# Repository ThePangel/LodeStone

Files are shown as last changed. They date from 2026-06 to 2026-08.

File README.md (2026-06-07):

# LodeStone

Don't lose your friends with this GPS LoRa P2P compass!

---

## The Idea 

### Where it came from
Just recently my district's fair started, and between all the crowds and the size of the fairgrounds It's pretty hard to find my friends, especially when we get separated, so with that and me playing a bunch of Minecraft this idea of a Mesh LoRa P2P compass came about.

The name is a reference to the lodestone block in Minecraft which lets you set custom compass targets.

---

### Features

- [ ] Compass like display pointing at the other nodes in the mesh network
- [ ] Top down map-like view of all nodes in the network
- [ ] Encrypted location data 
- [ ] Gesture based navigation using the gyroscope and accelerometer
- [ ] Short messages (Using some sort of keyboard using the gestures, or morse code)
- [ ] Heavily optimized battery life

---

### How would it work?
The device consists of 7 components:
- Seeed Studio XIAO ESP32 S3 Plus (As the brains of the device)
- Seeed Studio Lora32 SX1262 (For LoRa)
- Seeed Studio L76K GNSS Module (For GPS)
- GY-9250 BMP085 Module (For Accelerometer, Gyroscope and an actual compass)
- GC9A01 Round TFT screen 
- 503040 600mAh Battery
- Flexible antenna for the gps module (The standard ceramic one that comes with the module is far too bulky)

#### Connectivity 

The idea is that each node connects to each other individually or in groups, working simultaneously.

Pairing is done by a gesture password consisting of holds and taps, basically a morse code pin. You pair your devices using the same pin, then they handshake, share keys, and establish a connection.

Even if they are not paired (and if enabled), nodes retransmit incoming data packets to other users in the network to increase range.

#### Display 

The compass and map are drawn by taking GPS data from both nodes and the GY-9250 compass and accelerometer to calculate the direction the other node is at.

#### Battery

To optimize battery life and not saturate the airwaves, my system uses a Supply-demand approach. When the node (as a pendant or in the pocket) is still and facing away from the user, it is just listening for either location packets or a request packet. If it receives a location packet, it will update that node's location in memory and nothing else. If it receives a request packet, it will send its own location.

When the node is pulled up to be viewed, it will send a request packet to other nodes to update their location in memory, and a location packet so other nodes update it's location. It will do this at customizable intervals of time while it is being viewed. For signal integrity, the sending node must receive a confirmation packet back to ensure the transmission was successful. This workflow keeps battery usage to a minimum.

I still think it should ping at a set interval to guarante some type of connection, since maybe I can recieve my friends location, but he can't recieve my request so I knever know were he is
this could be also tied to speed using the accelerometer, this meaning, the more they move the more they send, if they are still it will default to some configurable interval

We could also tune transmition gain baised on distance, with some headroom of course

#### Interface

To maintain a compact formfactor, interaction with the node will be based on gestures, using the GY-9250 accelerometer and gyro.

Some of this gestures could be:
-   Tap/Double Tap
-   Shake
-   Tilt right/left/up/down

The menus would be similar to a smart watch.

#### Messaging

We can leverage our LoRa connection to send quick preconfigurable messages or write one at that moment using a gesture keyboard or morse code.

In the future I may develop an app to make this easier (tbh just use meshtashtic or meshcore atp), but this is intended for short notification like messages.

I would also like to add an SOS function that sends a signal to all nodes paired, or even if enabled on both ends, all nodes in the network, this will make the nodes flash red and highlight the SOS'ing node.

#### PCB 

The PCB is a simple 4 layer PCB that as compactly as possible houses all of the off the shelf components, making it very cheap and easy to assemble, the two outter planes hold traces and GND while the two inner layers are full ground pours, a bunch of vias connect the 4 GNDs to improve RF performance

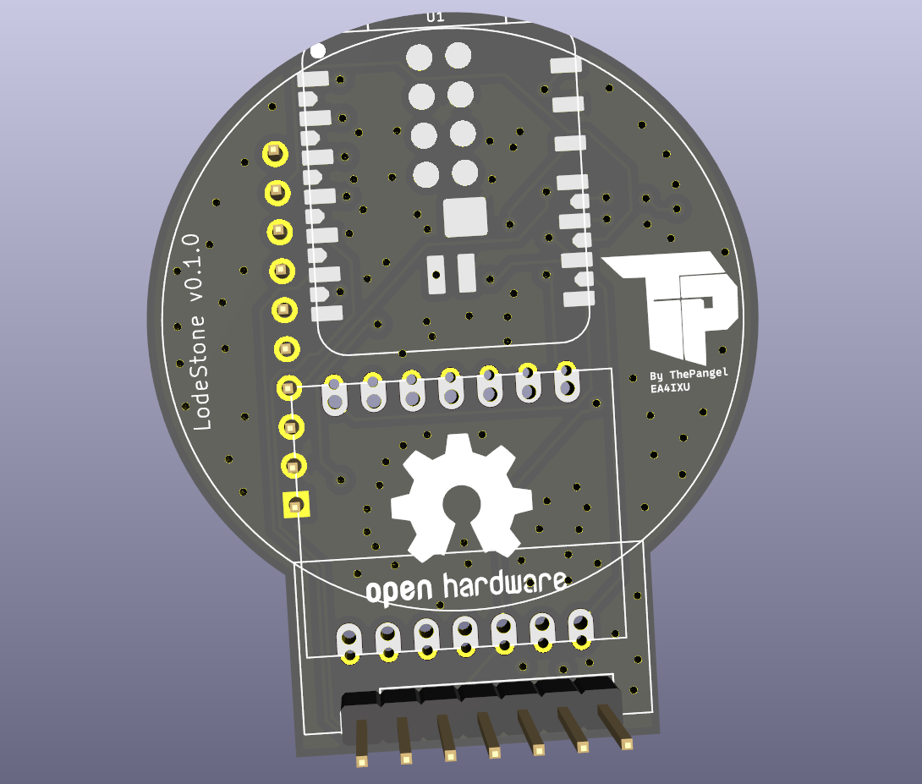
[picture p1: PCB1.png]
PCB1

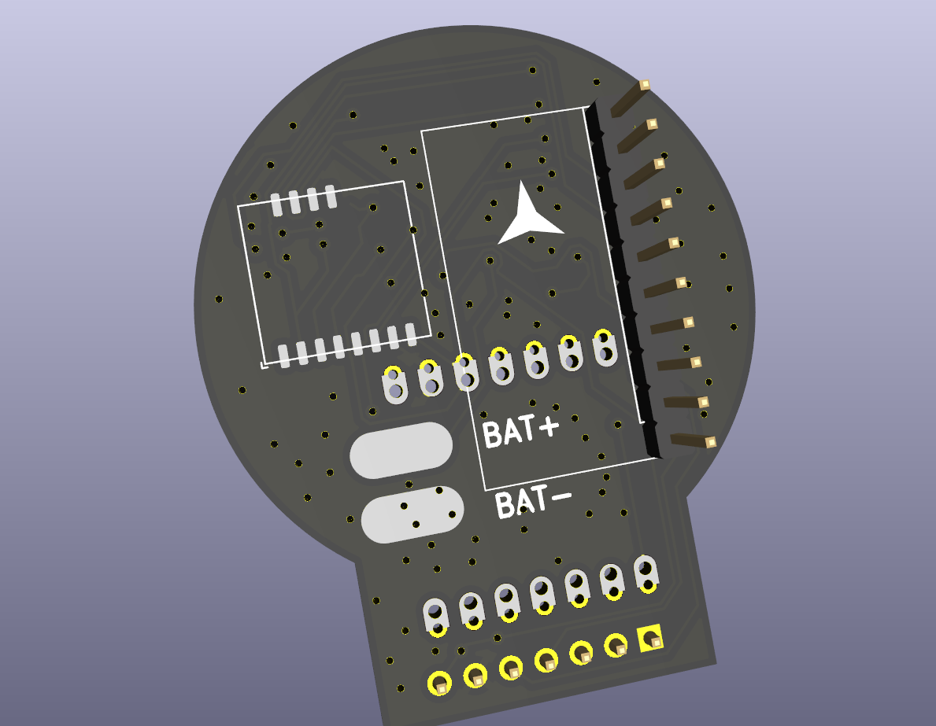
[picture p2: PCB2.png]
PCB2


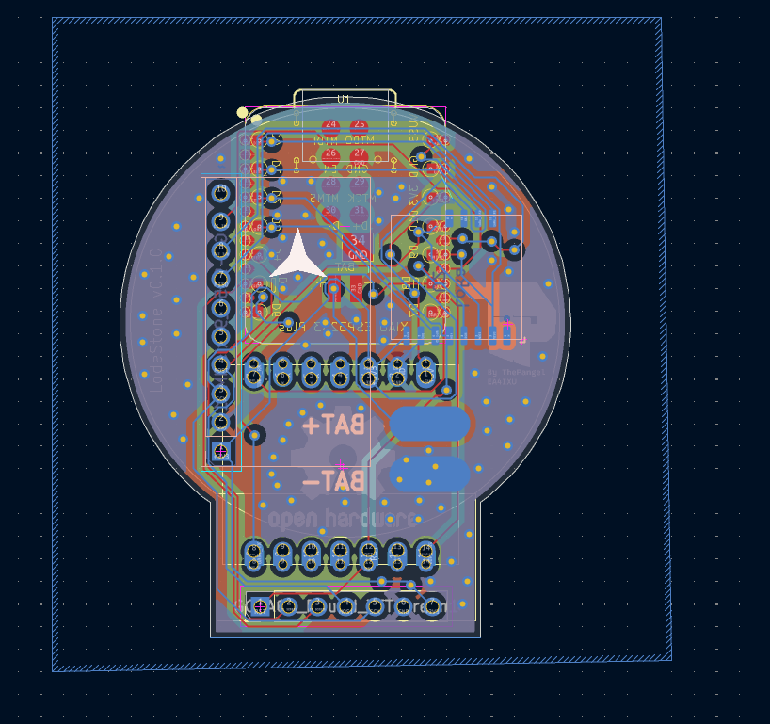
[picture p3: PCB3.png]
PCB3


#### 3D printed case

I will make a 3D printed case, as small and tight as possible for it to be portable and comfortable, of course anyone could design their own cases.

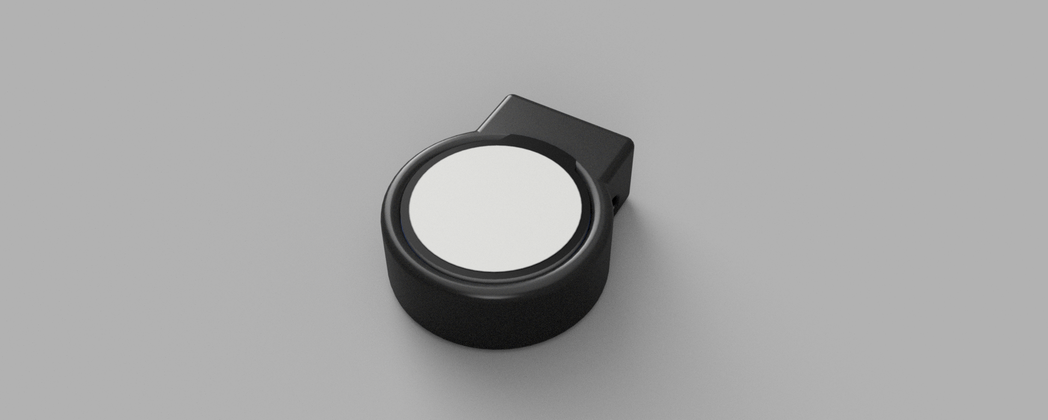
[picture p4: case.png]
CASE


#### FOSS and modularity

I would like this project to be modular and community focused, so I encourage colaboration integrating for example:
-   Other ESP or microcontroller models
-   Other screens
-   Extra input components
-   Other IMU

etc.. all from the same modular firmware.

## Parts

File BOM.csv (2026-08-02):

Item Name | Variant / Spec | Store | Quantity | Unit Price (€) | Subtotal (€) | Shipping Fee (€)
SX1262 Wireless Module 868MHz 915MHz 22dBm Wio-SX1262 | 1 pcs / China Mainland | Seeedstudio AI Hardware Store | 2 | 5.59 | 11.18 | 4.82
Seeed Studio XIAO ESP32 Development Board | XIAO ESP32S3 Plus / 1 piece | Seeedstudio AI Hardware Store | 2 | 9.59 | 19.18 | 6.31
3.7V 600mAh LiPo Batteries 503040 | 2 PCS / China Mainland | Camera Battery Store | 1 | 4.59 | 4.59 | 5.65
L76K GPS GNSS Module for XIAO | Standard | Seeedstudio AI Hardware Store | 2 | 13.59 | 27.18 | 6.31
2Pcs/lot 433/470/868/915 MHz Built-In PCB Antenna | BD-GPS soft built-in / 12CM / 1-pex1 | Zhongcheng Electronics Co., Ltd Store | 1 | 2.63 | 2.63 | 2.13
2PCS GSM 868MHz 915MHz FPC Built-In Soft Board Antenna | 2pcs IPEX1 | XYANT Wireless Store | 1 | 4.19 | 4.19 | 0.0
GY-9250 9-Axis Attitude / Compass Sensor Module | GY-9250 with pin | HHKFYD Module Store | 2 | 2.59 | 5.18 | 0.0
TFT Display 1.28 Inch Round RGB 240x240 LCD | 1.28 TFT Round | TENSTAR ROBOT Store | 2 | 3.29 | 6.58 | 0.0

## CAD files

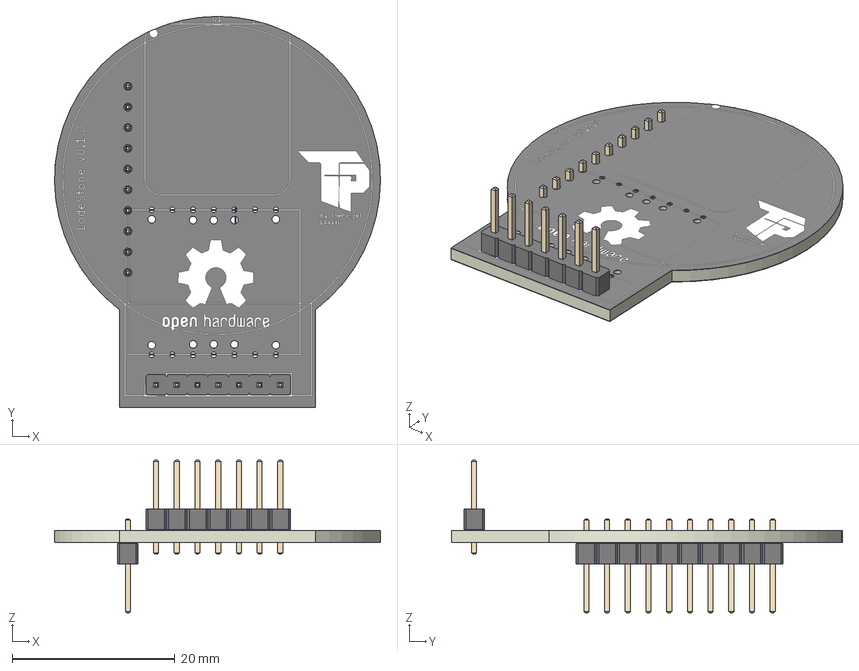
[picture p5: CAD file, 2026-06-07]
LodeStonePCB/.step
40.0 x 48.0 x 18.8 mm
PinHeader_1x07_P2.54mm_Vertical
PinHeader_1x10_P2.54mm_Vertical
LodeStonePCB_silkscreen x 2
LodeStonePCB_soldermask x 2
LodeStonePCB_PCB

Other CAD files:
LodeStonePCB/pcb.step

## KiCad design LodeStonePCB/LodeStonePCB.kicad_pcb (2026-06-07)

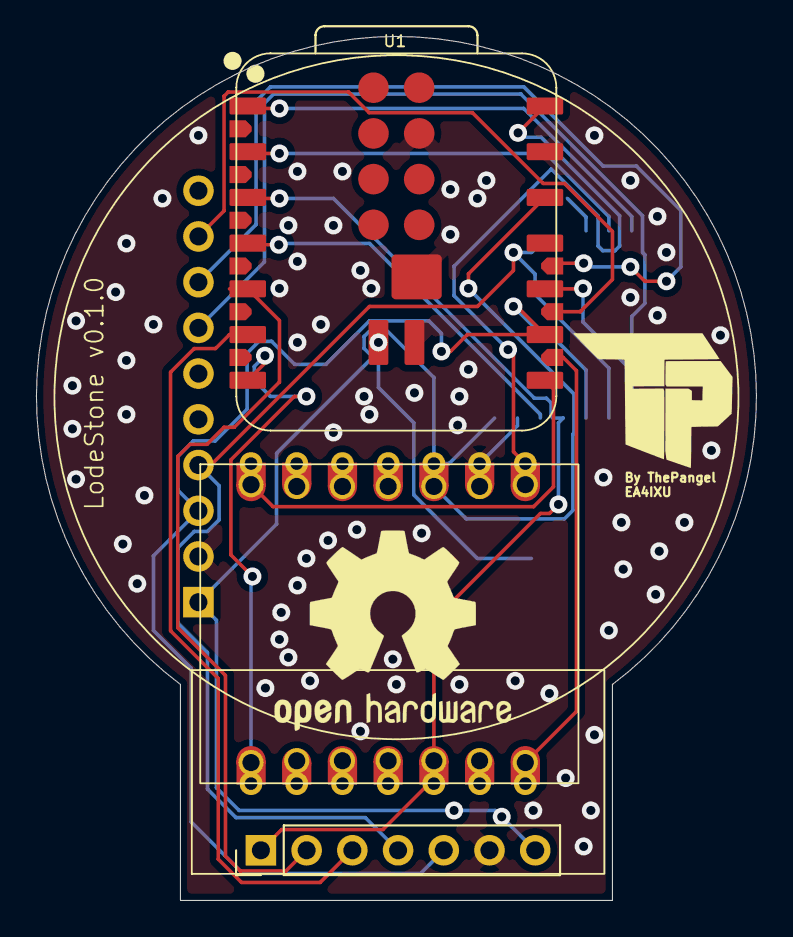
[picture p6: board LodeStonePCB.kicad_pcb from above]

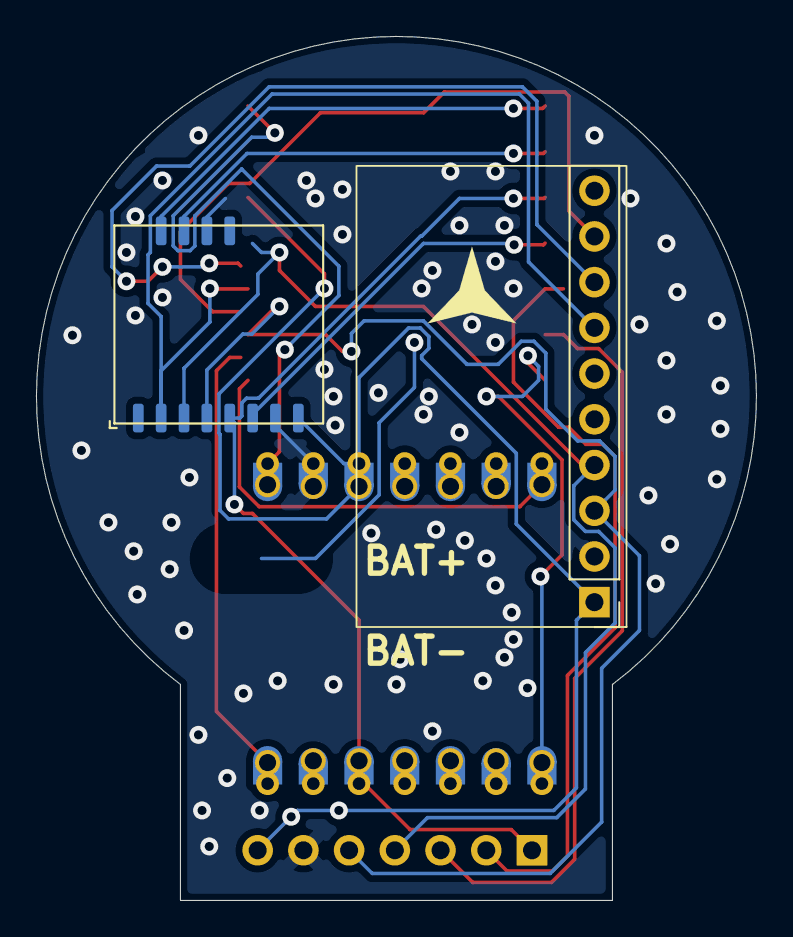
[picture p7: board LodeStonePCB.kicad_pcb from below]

Board: 4 copper layers, 40.0 x 48.0 mm, 5 parts (2 on the bottom side), 17 nets.

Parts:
GC9A01_Round_TFTscreen1: PinHeader_1x07_P2.54mm_Vertical
GY-9250_9Axis_IMU1: PinHeader_1x10_P2.54mm_Vertical
L76K_GNSS_Module1: XIAO-14P-Add-On
U1: XIAO-ESP32-S3-Plus-SMD
U2: LoRa; Wio-SX1262 PCB Package

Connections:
+3V3: GC9A01_Round_TFTscreen1.7 (VCC), GY-9250_9Axis_IMU1.1 (VCC), L76K_GNSS_Module1.3 (3V3), U1.12 (3V3), U2.8 (VCC)
+5V: L76K_GNSS_Module1.1 (5V), U1.14 (VBUS)
/CS_IMU: GY-9250_9Axis_IMU1.9 (NCS), U1.22 (GPIO12_DVP_Y7_SPI_MISO1)
/CS_LoRa: U1.4 (GPIO4_A3_D3), U2.6 (NSS)
/CS_SCREEN: GC9A01_Round_TFTscreen1.2 (CS), U1.5 (GPIO5_A4_D4_SDA)
/DC_SCREEN: GC9A01_Round_TFTscreen1.3 (DC), U1.6 (GPIO6_A5_D5_SCL)
/INT_IMU: GY-9250_9Axis_IMU1.8 (INT), U1.23 (GPIO13_DVP_PCLK_SPI_SCK1)
/LoRa_BUSY: U1.2 (GPIO2_A1_D1), U2.11 (BUSY)
/LoRa_DI01: U1.1 (GPIO1_A0_D0), U2.12 (DIO1)
/MISO: GY-9250_9Axis_IMU1.7 (ADO), U1.10 (GPIO8_A9_D9_MISO), U2.2 (MISO)
/MOSI: GC9A01_Round_TFTscreen1.4 (SDA), GY-9250_9Axis_IMU1.4 (SDA), U1.11 (GPIO9_A10_D10_MOSI), U2.3 (MOSI)
/RST: GC9A01_Round_TFTscreen1.1 (RST), L76K_GNSS_Module1.12 (RST), U1.3 (GPIO3_A2_D2), U2.5 (RST)
/SCK: GC9A01_Round_TFTscreen1.5 (SCL), GY-9250_9Axis_IMU1.3 (SCL), U1.9 (GPIO7_A8_D8_SCK), U2.4 (SCK)
/UART_RX: L76K_GNSS_Module1.7 (TX), U1.8 (GPIO44_D7_RX)
/UART_TX: L76K_GNSS_Module1.8 (RX), U1.7 (GPIO43_D6_TX)
/WUP_GNSS: L76K_GNSS_Module1.14 (WUP), U1.21 (GPIO11_DVP_Y8_SPI_MOSI1)
GND: GC9A01_Round_TFTscreen1.6 (GND), GY-9250_9Axis_IMU1.2 (GND), L76K_GNSS_Module1.2 (GND), U1.13 (GND), U1.27 (GND1), U1.33 (GND2), U1.34 (PAD), U2.7 (GND1), U2.10 (GND2)

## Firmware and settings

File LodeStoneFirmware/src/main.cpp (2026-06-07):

#include <Arduino.h>

// put function declarations here:
int myFunction(int, int);

void setup() {
  // put your setup code here, to run once:
  int result = myFunction(2, 3);
}

void loop() {
  // put your main code here, to run repeatedly:
}

// put function definitions here:
int myFunction(int x, int y) {
  return x + y;
}

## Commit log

2026-06-07 Started PCB
    [LodeStonePCB.kicad_pcb, LodeStonePCB.kicad_sch]
2026-06-07 Finished pcb
    [LodeStonePCB.kicad_pcb, LodeStonePCB.kicad_sch]
2026-06-07 Images to readme
    [.step, pcb.step]
2026-08-02 added BOM.csv for Stardance Funding
    This BOM is for TWO UNITS not one, this BOM is strictly for stardance funding
    [BOM.csv]
